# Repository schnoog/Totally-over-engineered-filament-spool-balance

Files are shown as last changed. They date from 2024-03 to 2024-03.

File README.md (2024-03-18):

# Totally-over-engineered-filament-spool-balance

## What it can and (hopefully soon) does

- Spool holder for 4 filament spools
- Each with a load cell to record the weight
- Temperature and humidity measurement
  - BME280 sensor
  - EEPROM saved control range (Lower and Upper level)
  - Switching of 2 digital GPIOs (Switching ON if > upper level, OFF is < lower level) I use for pumping air through a dehumidifier
- WiFi connection to my home network
- OTA (Over the air) update of the firmware
- Publishing the data to my MQTT server
- Waveshare 4.2Inch e-Paper module to show the data directly on the filament box
- Easy web frontend to 
  - Show all the data (weight, set spool weights, temperature, humidity, upper and lower humidity level)
  - Set upper and lower control range
  - Switch the pumps automatic on/off
  - Switch the pumps on/off
  - Tare each balance
  - Calibrate each balance (1000g calibration weight)
  - set the spool type between 
    - Material4Print-750g spools
    - Overture 1000g spools (A friend gave me a spool of TPU, normally I only use M4P)

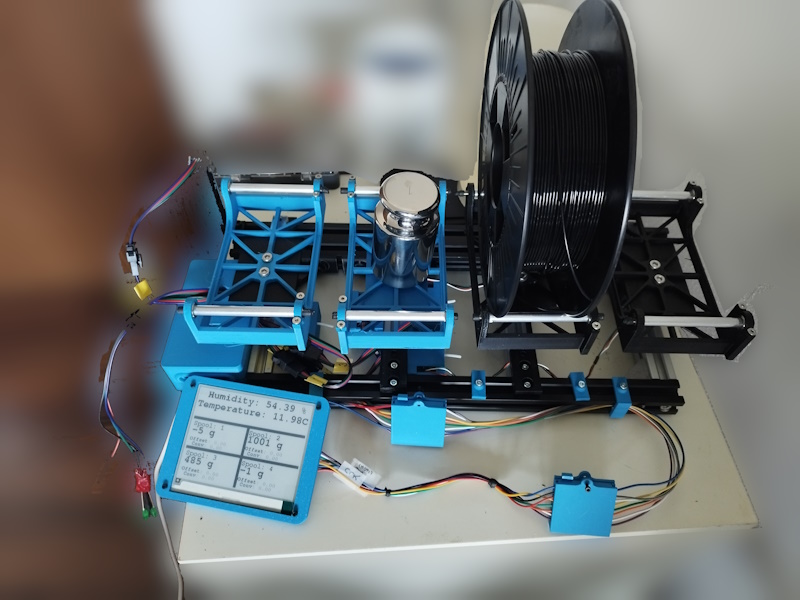
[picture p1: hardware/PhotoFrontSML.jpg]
How it looks like


## Background
I have a 3D printer and a filament storage box which keeps the filament dry. The printer is fed directly out of the box.

Filament box is on top of an IKEA Lack table, below the printer. A hole drilled through the filament box and the 5cm "wook" of the lack, lined with a PTFE tube allows me to do so.

The filament spool is on a holder with an integrated load cell which gives me the weight of the spool to not have to guess whether the filament is sufficients for the print or not.

That's working and I could be happy.

Yeah, could.

But....
I do often switch between filaments, which mean I have to not only unload the filament from the 3D printer, but also pull it back into the box, enter the new filament through the PFTE liner, place the spool on the balance, record the weight of the empty spool (I only have 2 manufacturers material, so that's not difficult), enter it into my system.
But that means the filament box is open for a minute or so, has air exchange with the room, humidity increases...

## Hardware

The 3D printed parts I used can be sound in the hardware/stls directory.

Beside of the 3D printed part (and a few screws and wires) I used the following things:
- 16 685ZZ beatings
- 8 x  90mm pieces of M5 thread
- 8 x  70mm alu pipe ID:5mm , 1mm wall thickness
- 4 12.7x12.7x80mm 3kg load cells with HX711 boards
- A Lolin S3 ESP32 S3 dev board
- A Waveshare 4.2inch e-Paper-module (I bought some years ago)
- A BME280 sensor breakout board
- Aluminium extrusion
  - 4 x 120mm 2020
  - 1 x 330mm 2020 
  - 1 x 400mm 2040
  - Corner connectors and t-nuts

Tools I used
- electric screwdriver
- M3 screw tap
- allen keys

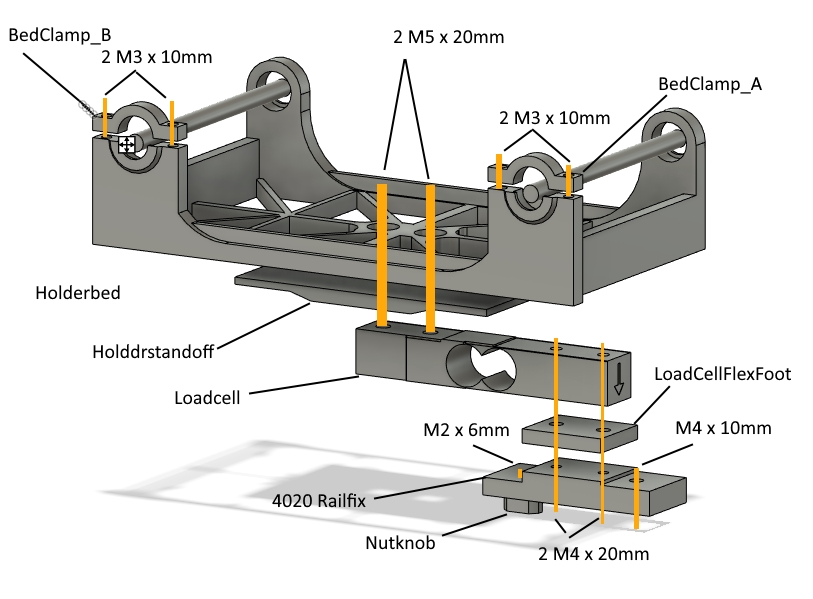
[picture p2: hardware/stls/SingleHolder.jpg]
A single spool holder


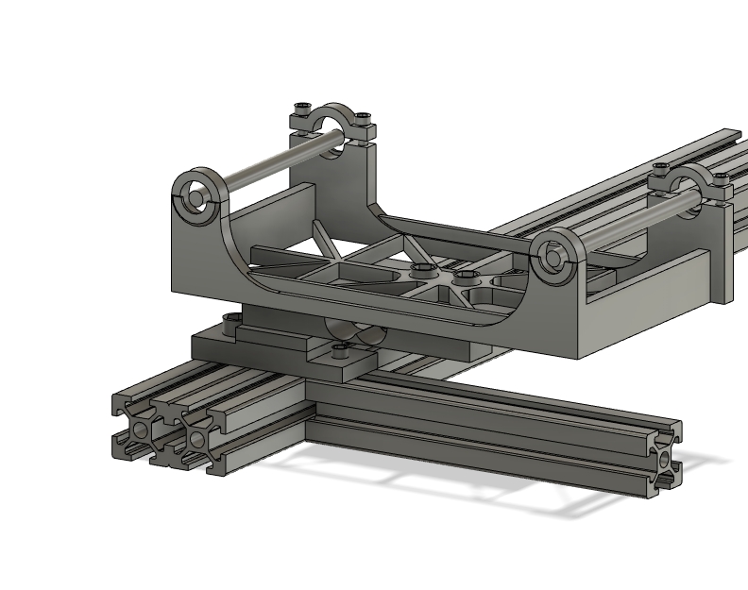
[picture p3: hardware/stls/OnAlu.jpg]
On the rail


### And that's the frontend, ugly, isn't it?
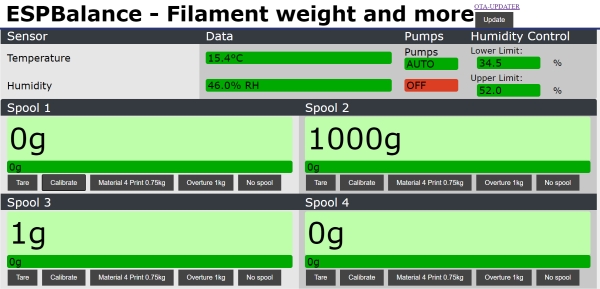
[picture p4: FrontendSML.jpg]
FrontEnd


### More about the humidity
I attached a 5V PWM laptop fan so that GPIO47 is used to switch the fan on and off. 
With said fan I pump air from my filament chamber through a TPU hose into an air drying box which then flows back through another hose into my chamber.

As soon as the humidity in the chamber exceeds to upper control limit for more than 60 seconds the fan is started until the humidity remains for 30 seconds below the lower control limit. 

Yes, I could implement a PID... but at the moment I'm quite happy.  The data is sent in a 15 seconds interval to my mqtt broker.  

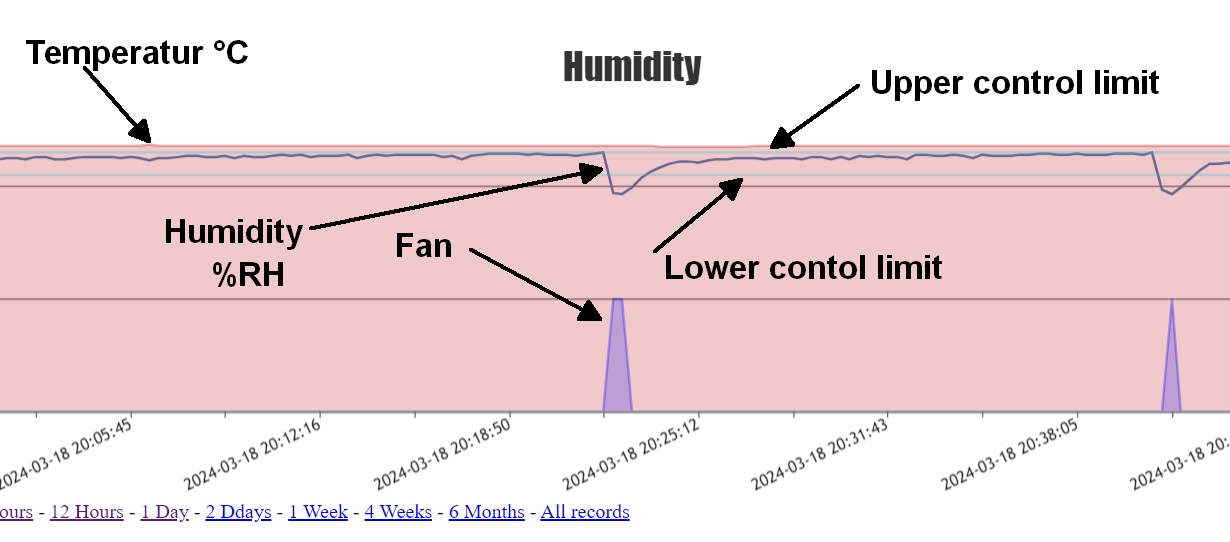
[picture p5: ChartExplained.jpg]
ChartExplained


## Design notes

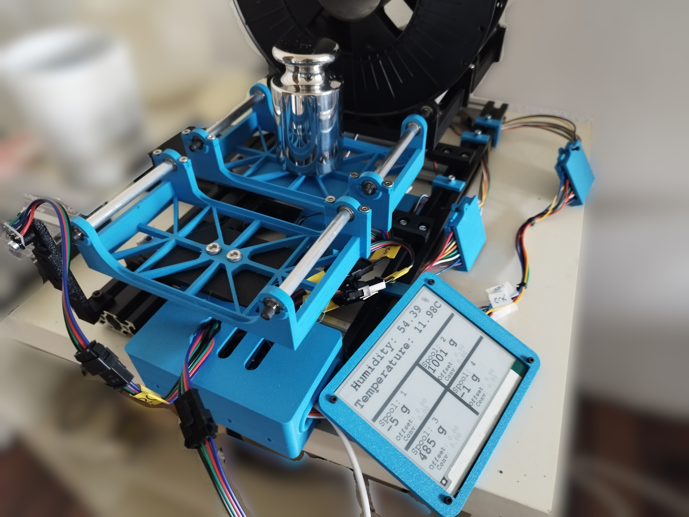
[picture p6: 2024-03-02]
hardware/PhotoSide.jpg

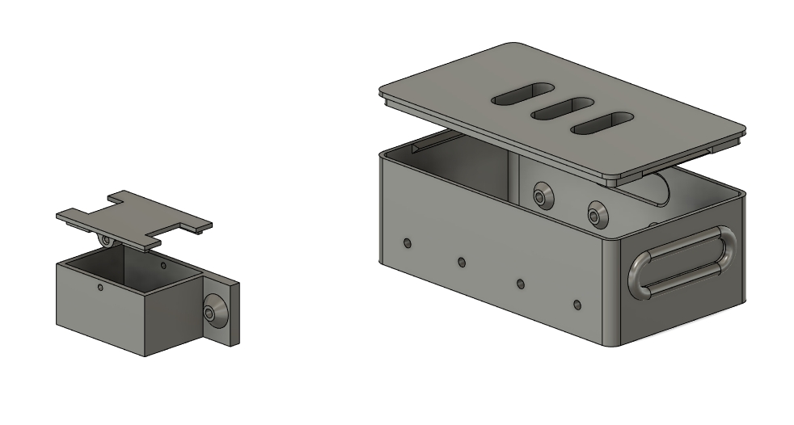
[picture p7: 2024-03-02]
hardware/stls/ESPandHX711Holder.jpg

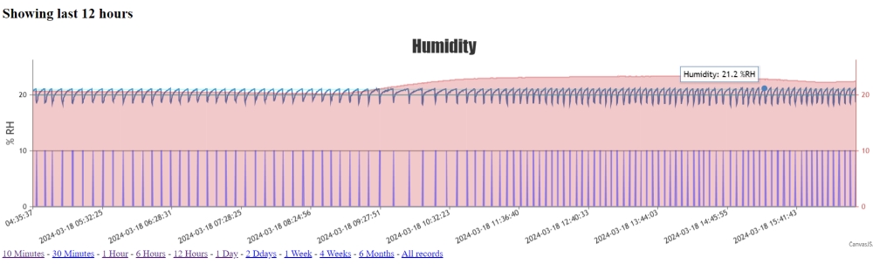
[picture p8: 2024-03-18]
ControlchartSML.jpg

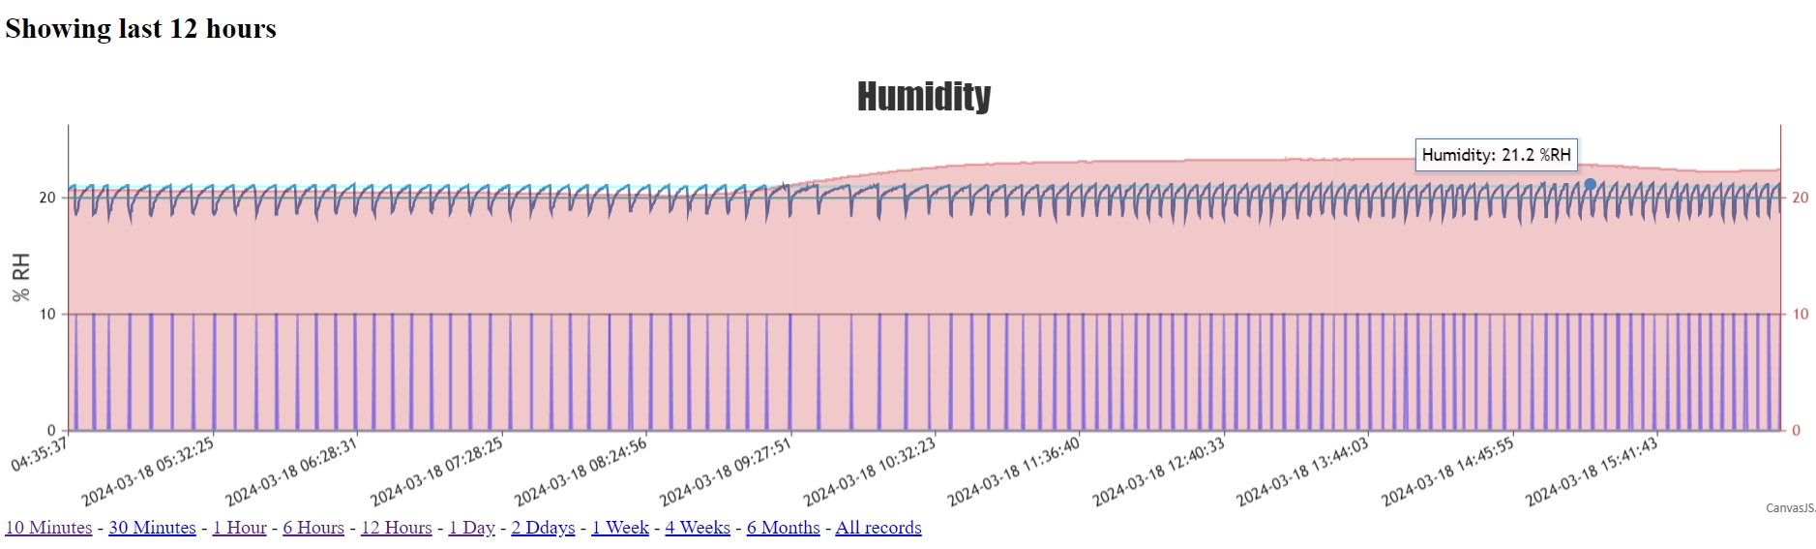
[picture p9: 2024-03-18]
Controlchart.jpg

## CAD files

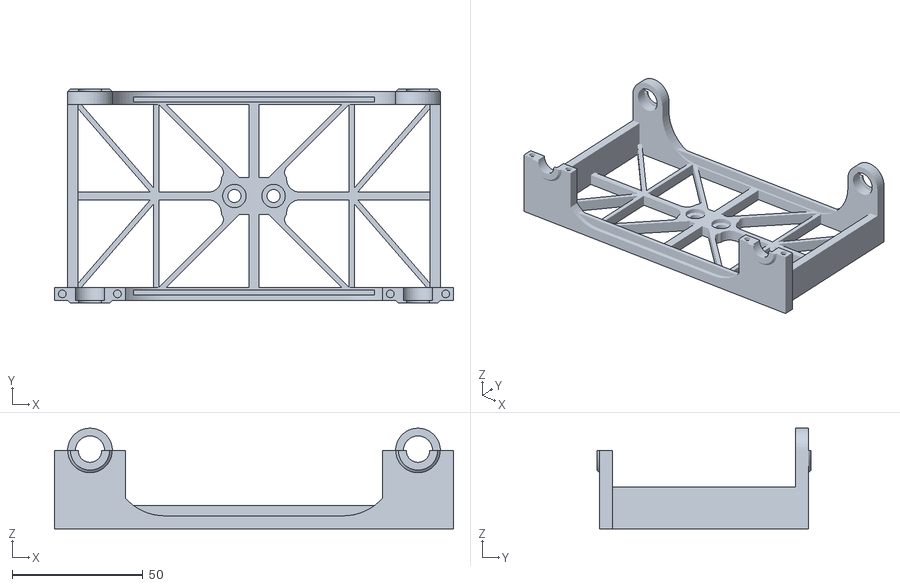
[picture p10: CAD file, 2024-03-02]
hardware/stls/HolderBed.stl
152.9 x 82.0 x 38.6

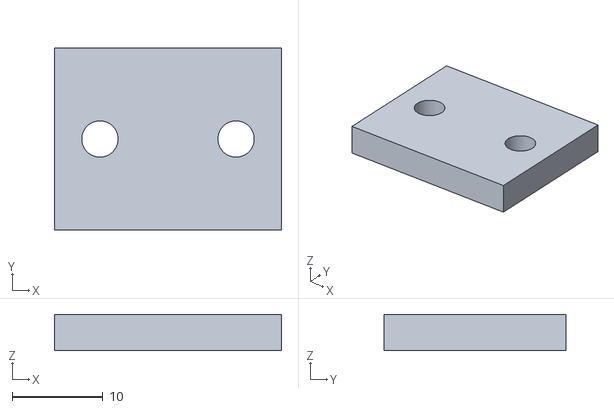
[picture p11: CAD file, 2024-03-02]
hardware/stls/LoadCellFlexFoot.stl
25.0 x 20.0 x 4.00

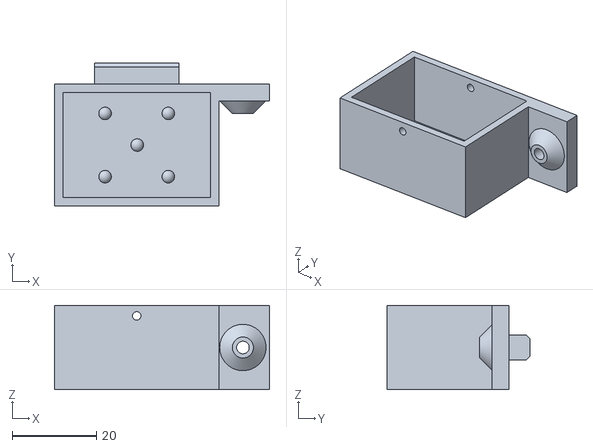
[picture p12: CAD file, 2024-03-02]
hardware/stls/HX711Holder_Box.stl
51.0 x 34.0 x 20.0

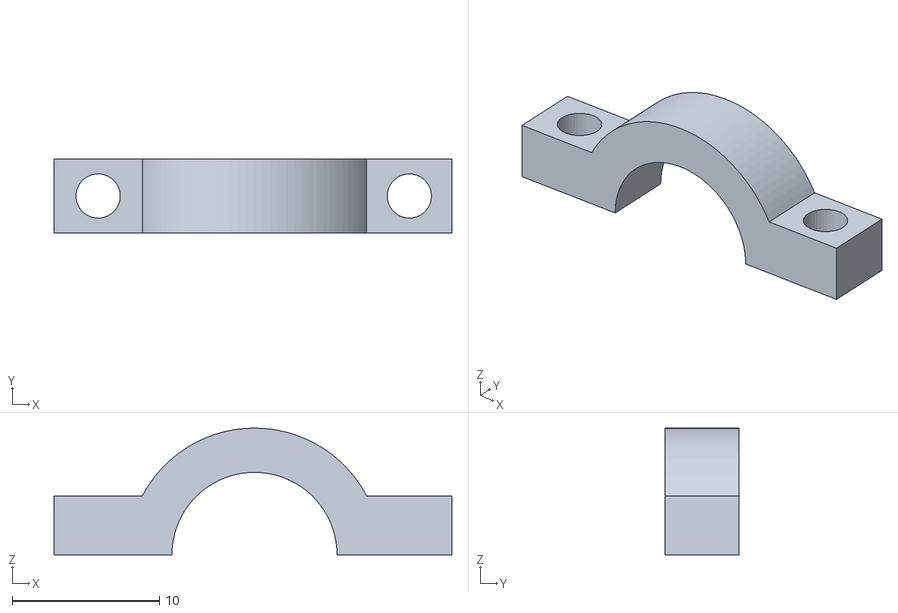
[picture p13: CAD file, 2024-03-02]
hardware/stls/BedClamp_A.stl
27.0 x 5.00 x 8.60

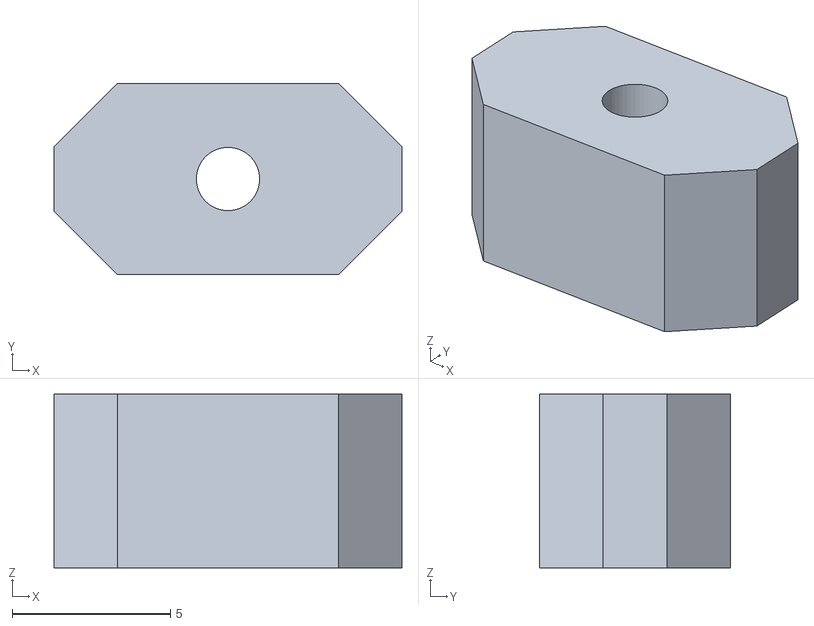
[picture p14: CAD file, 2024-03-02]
hardware/stls/Nutnob.stl
11.0 x 6.03 x 5.50

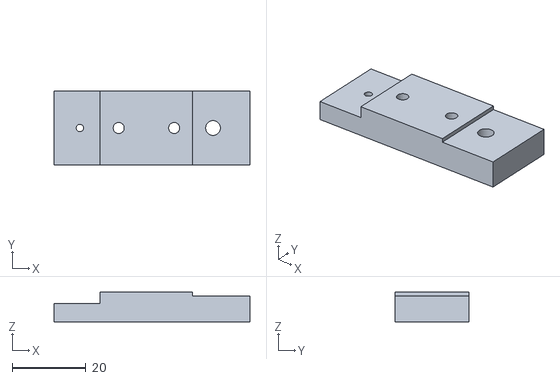
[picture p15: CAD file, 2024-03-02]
hardware/stls/4020Railfix.stl
53.0 x 20.0 x 8.00

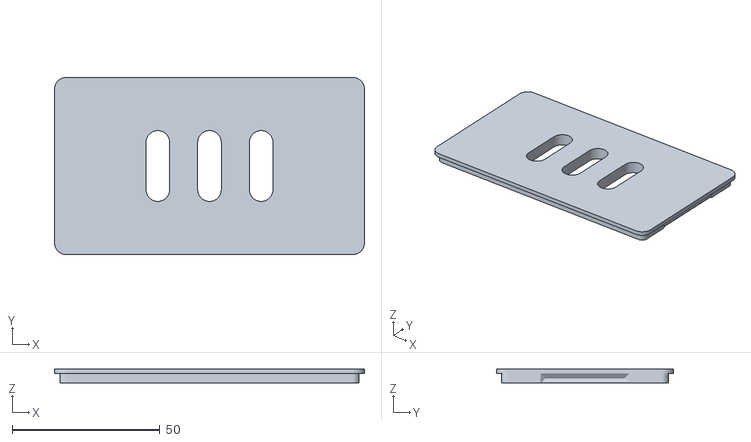
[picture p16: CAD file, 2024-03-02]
hardware/stls/ESP32Holder_LID.stl
105.0 x 60.0 x 4.80

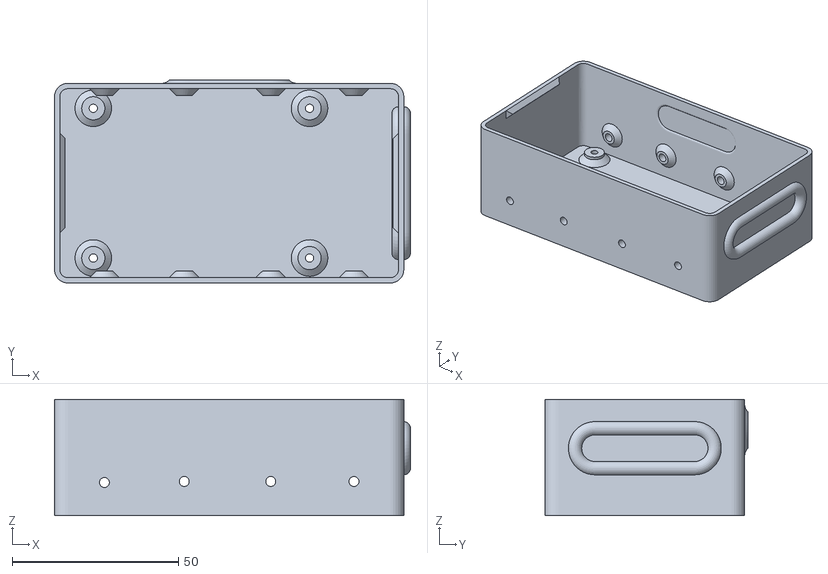
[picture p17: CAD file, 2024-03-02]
hardware/stls/ESP32Holder_BOX.stl
107.0 x 61.0 x 35.0

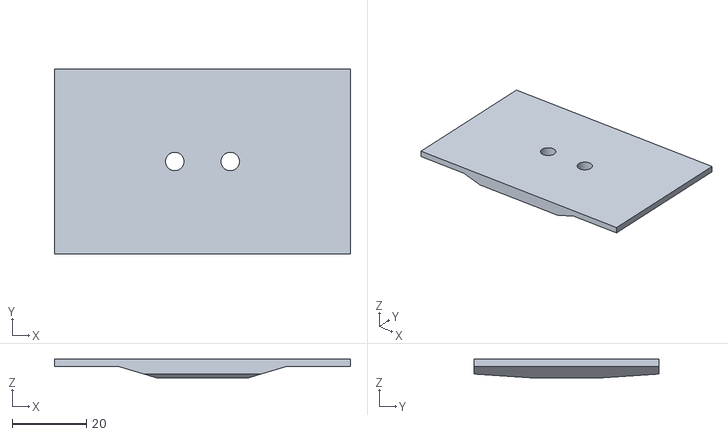
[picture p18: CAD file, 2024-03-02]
hardware/stls/Holderstandoff.stl
80.0 x 50.0 x 5.00

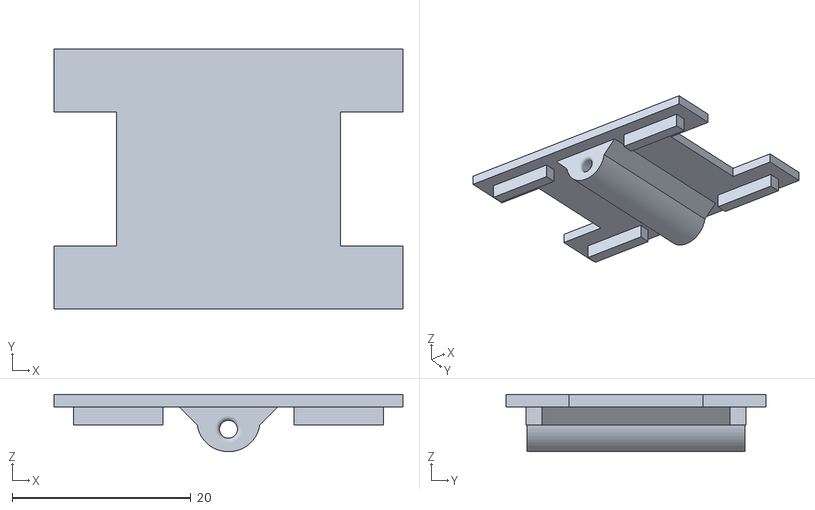
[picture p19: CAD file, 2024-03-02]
hardware/stls/HX711Holder_LID.stl
39.0 x 29.0 x 6.40

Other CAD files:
hardware/stls/2020LoadCellFix.stl

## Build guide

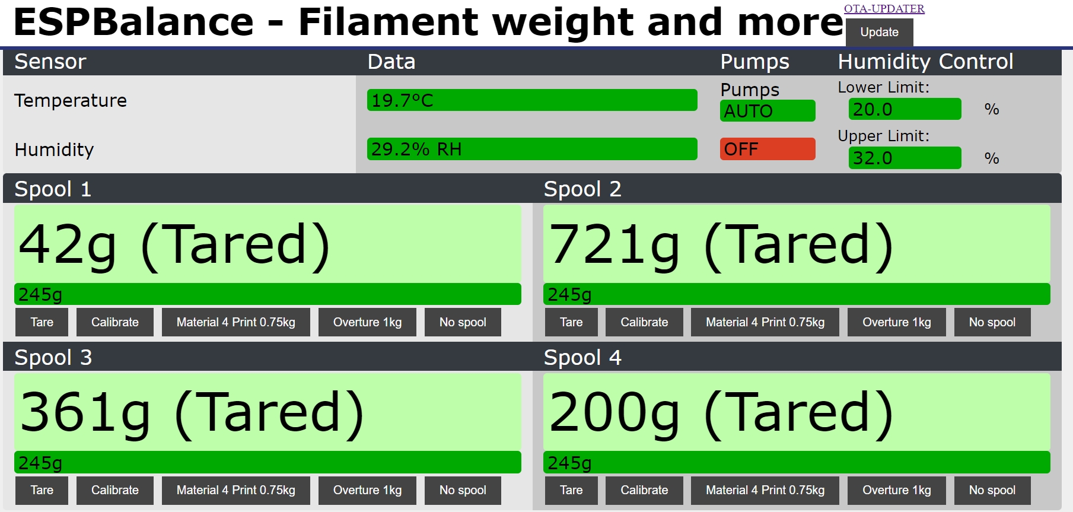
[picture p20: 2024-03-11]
Frontend_Installed.jpg

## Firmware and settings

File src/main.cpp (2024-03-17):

#include <Arduino.h>
#include <EEPROM.h>
#include <Adafruit_NeoPixel.h>

#define USE_EPAPER



#include <serial_cmds.h>
#include <homewifi.h>

#ifdef USE_EPAPER
  #include <displayinit.h>
  #include <displaydemo.h>
#endif

#include <locadcell.h>
#include <humidity.h>

#ifdef USE_EPAPER
  #include <output_display.h>
#endif


#include <neoled.h>
#include <remotework.h>
#include <webfrontend.h>






void setup()
{
  EEPROM.begin(512);
  LED_setup();
  Serial.begin(115200);
  delay(1000);
  wifi_setup();
  SetupBalances();
  Serial.println();
#ifdef USE_EPAPER
  ePaper_setup();
#endif
  SerialCommandSetup();
  Serial.println("setup done");
#ifdef USE_EPAPER
  InfoPrintLn("Setup done");
#endif
  bme_setup();

PaintWeights();
//PaintDev();
}

void loopx(){
  //scan();
}

int subcount = 5;
void loop()
{
  wifi_loop();
  sCmd.readSerial();
  
#ifdef USE_EPAPER
  PaintWeights();
#endif
  const int serialPrintInterval = 1500; //increase value to slow down serial print activity
  // get smoothed value from the dataset:
  ReadLoadCells();

    if (millis() > t + serialPrintInterval) {
      t = millis();
        bme_loop(); 
        subcount++;
        if(subcount > 9){
                PublishWeights();
                subcount = 0;
        }


    }
  

}

// note for partial update window and setPartialWindow() method:
// partial update window size and position is on byte boundary in physical x direction
// the size is increased in setPartialWindow() if x or w are not multiple of 8 for even rotation, y or h for odd rotation
// see also comment in GxEPD2_BW.h, GxEPD2_3C.h or GxEPD2_GFX.h for method setPartialWindow()

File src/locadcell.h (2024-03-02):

#pragma once
#include <HX711_ADC.h>



#define HX1_SCK  48
#define HX1_DAT  45


//const int HX_DAT[] = {2, 3, 4, 5};  // Example pins, adjust as per your setup
//const int HX_SCK[] = {6, 7, 8, 9};  // Example pins, adjust as per your setup

//const int HX_DAT[] = {45};  // Example pins, adjust as per your setup
//const int HX_SCK[] = {48};  // Example pins, adjust as per your setup

const int HX_DAT[] = {7,5,16,18};  // Example pins, adjust as per your setup
const int HX_SCK[] = {6,4,15,17};  // Example pins, adjust as per your setup

//const int HX_SCK[] = {4,6,15,17};  // Example pins, adjust as per your setup
//const int HX_DAT[] = {5,7,16,18};  // Example pins, adjust as per your setup

//const int NUM_LOAD_CELLS = 1;
const int NUM_LOAD_CELLS = 4;
int MSAMPLES = 2;


HX711_ADC *loadCells[NUM_LOAD_CELLS];


//HX711_ADC LoadCell_1(HX1_DAT, HX1_SCK);
const int calVal_eepromAdress = 0;
unsigned long t = 0;

float Weight1 = 0;
float Weight2 = 0;
float Weight3 = 0;

float Weights[NUM_LOAD_CELLS];
int WeightInG[NUM_LOAD_CELLS];
float TaraOffSet[NUM_LOAD_CELLS];
float ConvFactor[NUM_LOAD_CELLS];
int EmptySpool[NUM_LOAD_CELLS];


#define EEPROM_ADDR_WEIGHT1 0
#define EEPROM_ADDR_WEIGHT2 sizeof(float)
#define EEPROM_ADDR_WEIGHT3 2*sizeof(float)
#define EEPROM_ADDR_WEIGHT4 3*sizeof(float)
#define EEPROM_ADDR_TARA1 4*sizeof(float)
#define EEPROM_ADDR_TARA2 5*sizeof(float)
#define EEPROM_ADDR_TARA3 6*sizeof(float)
#define EEPROM_ADDR_TARA4 7*sizeof(float)
#define EEPROM_ADDR_CALOFF1 8*sizeof(float)
#define EEPROM_ADDR_CALOFF2 9*sizeof(float)
#define EEPROM_ADDR_CALOFF3 10*sizeof(float)
#define EEPROM_ADDR_CALOFF4 11*sizeof(float)

#define EEPROM_ADDR_SPOOL1 14*sizeof(float)
#define EEPROM_ADDR_SPOOL2 15*sizeof(float)
#define EEPROM_ADDR_SPOOL3 16*sizeof(float)
#define EEPROM_ADDR_SPOOL4 17*sizeof(float)



//   AddWeight = (NUM - 1) * sizeof(float)
//   AddTara = (NUM + 3) * sizeof(float)
//   AddCalOff = (NUM + 7) * sizeof(float)





void RemoteCalibrateBalance(int BalanceNo){
    float CalWeight = 1000.00;
    int Chan = BalanceNo - 1;
    int AddCalOff = (Chan + 8) * sizeof(float);
    loadCells[Chan]->setCalFactor(1.0); 
    while (!loadCells[Chan]->update());
    float known_mass = CalWeight;
    loadCells[Chan]->refreshDataSet(); //refresh the dataset to be sure that the known mass is measured correct
    float newCalibrationValue = loadCells[Chan]->getNewCalibration(known_mass); //get the new calibration value
    EEPROM.put(AddCalOff, newCalibrationValue);
    EEPROM.commit();
    EEPROM.get(AddCalOff, newCalibrationValue);
}






















void SaveSpoolTaras(){
    int AddTara;
    for (int i = 0; i < NUM_LOAD_CELLS; ++i) {
         AddTara = (i + 14) * sizeof(float);
         EEPROM.put(AddTara,EmptySpool[i] );
         EEPROM.commit();
    }
}

void LoadSpoolTaras(){
    int TaraX = 0;
    int AddTara;
    for (int i = 0; i < NUM_LOAD_CELLS; ++i) {
         AddTara = (i + 14) * sizeof(float);
         EEPROM.get(AddTara,TaraX);
         EmptySpool[i] = TaraX;
    }
}

void TaraBalance( int BalanceNo){
    long _offset = 0;
    loadCells[BalanceNo -1]->tare();
    _offset = loadCells[BalanceNo -1]->getTareOffset();
    int AddTara = (BalanceNo + 3) * sizeof(float);
    Serial.print("Tara value of Balance ");
    Serial.print(BalanceNo);
    Serial.print(" : ");
    Serial.println(_offset);
    EEPROM.put(AddTara, _offset);
    EEPROM.commit();
    loadCells[BalanceNo -1]->setTareOffset(_offset);
}

void LoadTaras(){
    long _offset = 0;
    for (int i = 0; i < NUM_LOAD_CELLS; ++i) {
        int AddTara = (i + 4) * sizeof(float);
        
        EEPROM.get(AddTara,_offset);
        TaraOffSet[i] = _offset;
        Serial.print("Zeropoint ");
        Serial.print(i + 1);
        Serial.print(" : ");
        Serial.println(_offset);
        if(_offset != 0) loadCells[i]->setTareOffset(_offset);
         _offset = 0;
    }
}

void LoadCalibrations(){
    int AddCalOff = 0;
    float newCalibrationValue;
    for (int i = 0; i < NUM_LOAD_CELLS; ++i) {
        AddCalOff = (i + 8) * sizeof(float);
        EEPROM.get(AddCalOff, newCalibrationValue);
        Serial.print("Load Cal ");
        Serial.print(i +1);
        Serial.print(" : ");
        Serial.println(newCalibrationValue);
        ConvFactor[i] = newCalibrationValue;
        if(newCalibrationValue < 1) newCalibrationValue = 0;
        loadCells[i]->setCalFactor(newCalibrationValue);
    }
}


void CalibrateBalance(int BalanceNo){
    
    
    int Chan = BalanceNo - 1;
    int AddCalOff = (Chan + 8) * sizeof(float);
    TaraBalance(BalanceNo);
    loadCells[Chan]->setCalFactor(1.0); 
    while (!loadCells[Chan]->update());
    Serial.println("***");
    Serial.println("Start calibration:");
    Serial.println("Place the load cell an a level stable surface.");
    Serial.println("Remove any load applied to the load cell.");
    Serial.println("Send 't' from serial monitor to set the tare offset.");

    boolean _resume = false;
    while (_resume == false) {
        loadCells[Chan]->update();
        if (Serial.available() > 0) {
        if (Serial.available() > 0) {
            char inByte = Serial.read();
            if (inByte == 't') loadCells[Chan]->tareNoDelay();
        }
        }
        if (loadCells[Chan]->getTareStatus() == true) {
        Serial.println("Tare complete");
        _resume = true;
        }
    }    


    Serial.println("Now, place your known mass on the loadcell.");
    Serial.println("Then send the weight of this mass (i.e. 100.0) from serial monitor.");

    float known_mass = 0;
    _resume = false;
    while (_resume == false) {
        loadCells[Chan]->update();
        if (Serial.available() > 0) {
        known_mass = Serial.parseFloat();
        if (known_mass != 0) {
            Serial.print("Known mass is: ");
            Serial.println(known_mass);
            _resume = true;
        }
        }
    }


    loadCells[Chan]->refreshDataSet(); //refresh the dataset to be sure that the known mass is measured correct
    float newCalibrationValue = loadCells[Chan]->getNewCalibration(known_mass); //get the new calibration value

    Serial.print("New calibration value has been set to: ");
    Serial.print(newCalibrationValue);
    Serial.println(", use this as calibration value (calFactor) in your project sketch.");
    Serial.print("Save this value to EEPROM adress ");
    Serial.print(AddCalOff);
    Serial.println("? y/n");


  _resume = false;
  while (_resume == false) {
    if (Serial.available() > 0) {
      char inByte = Serial.read();
      if (inByte == 'y') {

        EEPROM.put(AddCalOff, newCalibrationValue);
        EEPROM.commit();
        EEPROM.get(AddCalOff, newCalibrationValue);
        Serial.print("Value ");
        Serial.print(newCalibrationValue);
        Serial.print(" saved to EEPROM address: ");
        Serial.println(calVal_eepromAdress);
        _resume = true;
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

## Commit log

2024-02-28 LoadCells functional, Tare to be adjusted, as well as calibration. BME280 provides Temperature and Humidity
2024-02-29 all 4 balances working with tare and calibration
2024-03-01 To pins as output for pumps defined... not much more happened
2024-03-02 add some stls and images
    [2020LoadCellFix.stl, 4020Railfix.stl, BedClamp_A.stl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]
2024-03-09 Added IO47 as PWM output to drive a 5v fan
2024-03-15 publication of pumpstate
